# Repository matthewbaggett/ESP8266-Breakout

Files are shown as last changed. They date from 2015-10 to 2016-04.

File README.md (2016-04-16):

# ESP8266 Breakout

Originally just a ESP8266 broken out onto a 22pin DIP header, has become an ESP8266 on a 24pin DIP header with built in 3.3v regulator ([AMS1117](http://www.aliexpress.com/premium/ams1117.html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)), and built-in USB programmer ([CH340G](http://www.aliexpress.com/item/Free-shipping-50pcs-lot-CH340G-CH340-SOP16-IC-Best-quality/32420752742.html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)) and all the associated recommended pullups as per the [Arduino ESP8266 project](https://github.com/esp8266/Arduino) ([Schematic](https://github.com/esp8266/Arduino/blob/esp8266/docs/ESP_improved_stability.png)

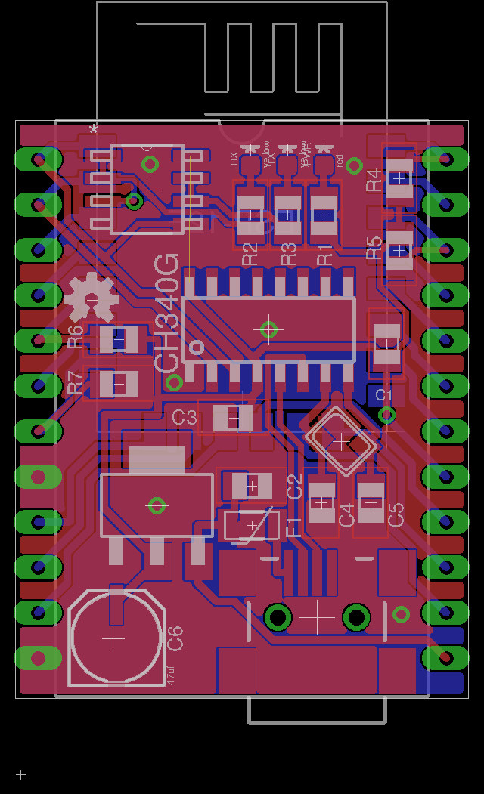
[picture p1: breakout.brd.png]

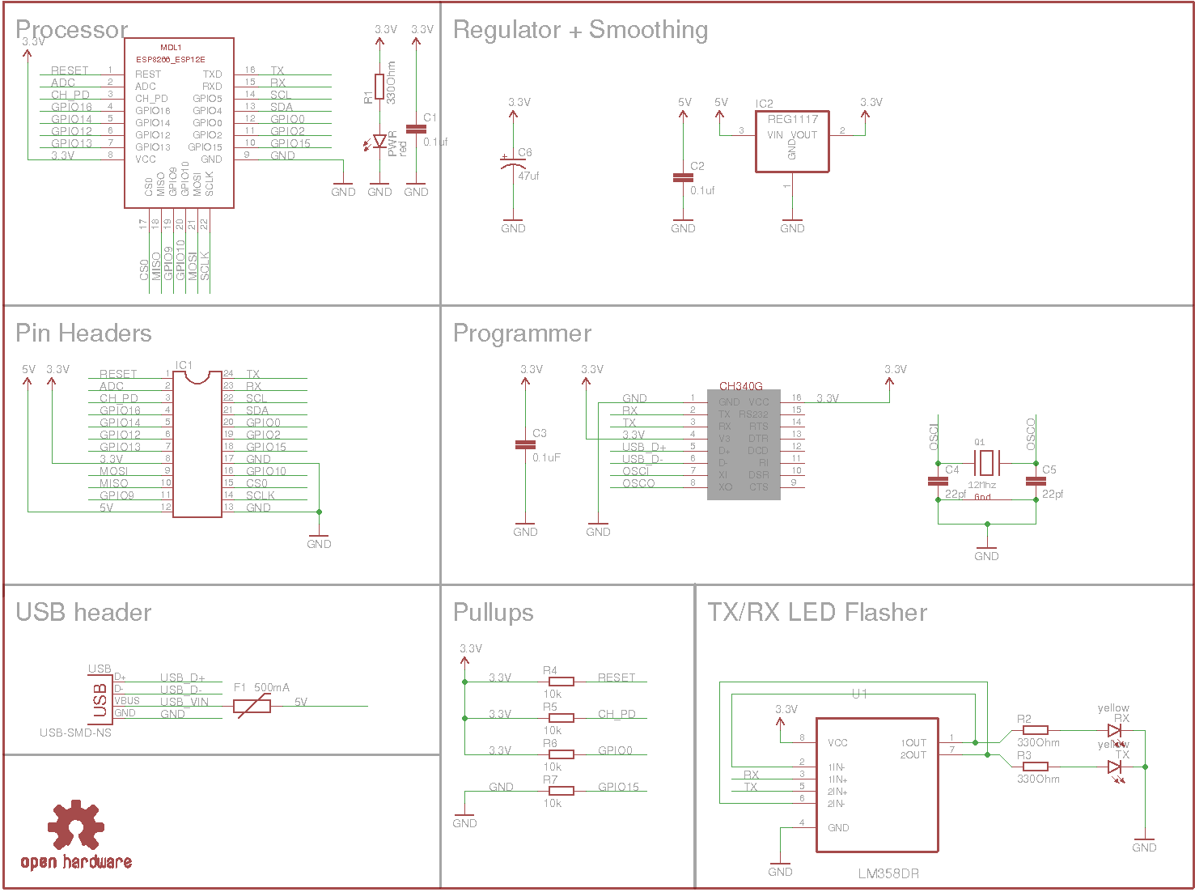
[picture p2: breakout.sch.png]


# Licence

<br />This work is licensed under a <a rel="license" href="http://creativecommons.org/licenses/by-nc/4.0/">Creative Commons Attribution-NonCommercial 4.0 International License</a>.

May be re-licenced on request.

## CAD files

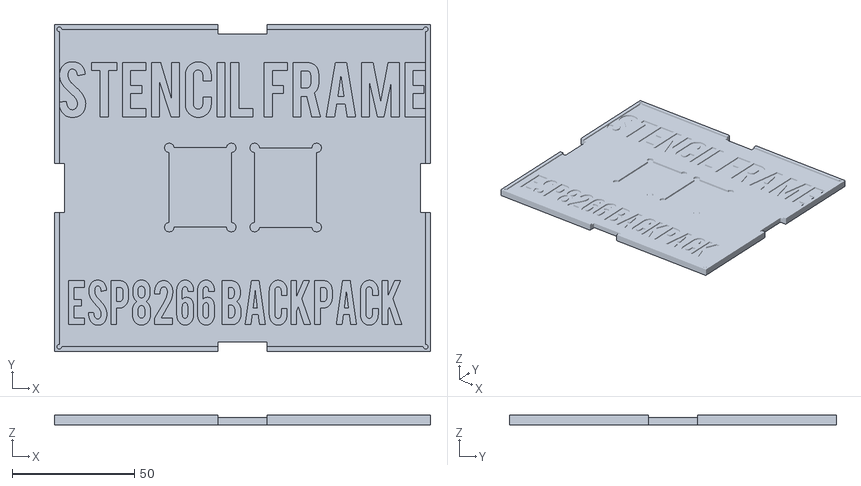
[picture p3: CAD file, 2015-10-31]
stencil_frame_esp8266_backpack.stl
154.0 x 134.0 x 4.00

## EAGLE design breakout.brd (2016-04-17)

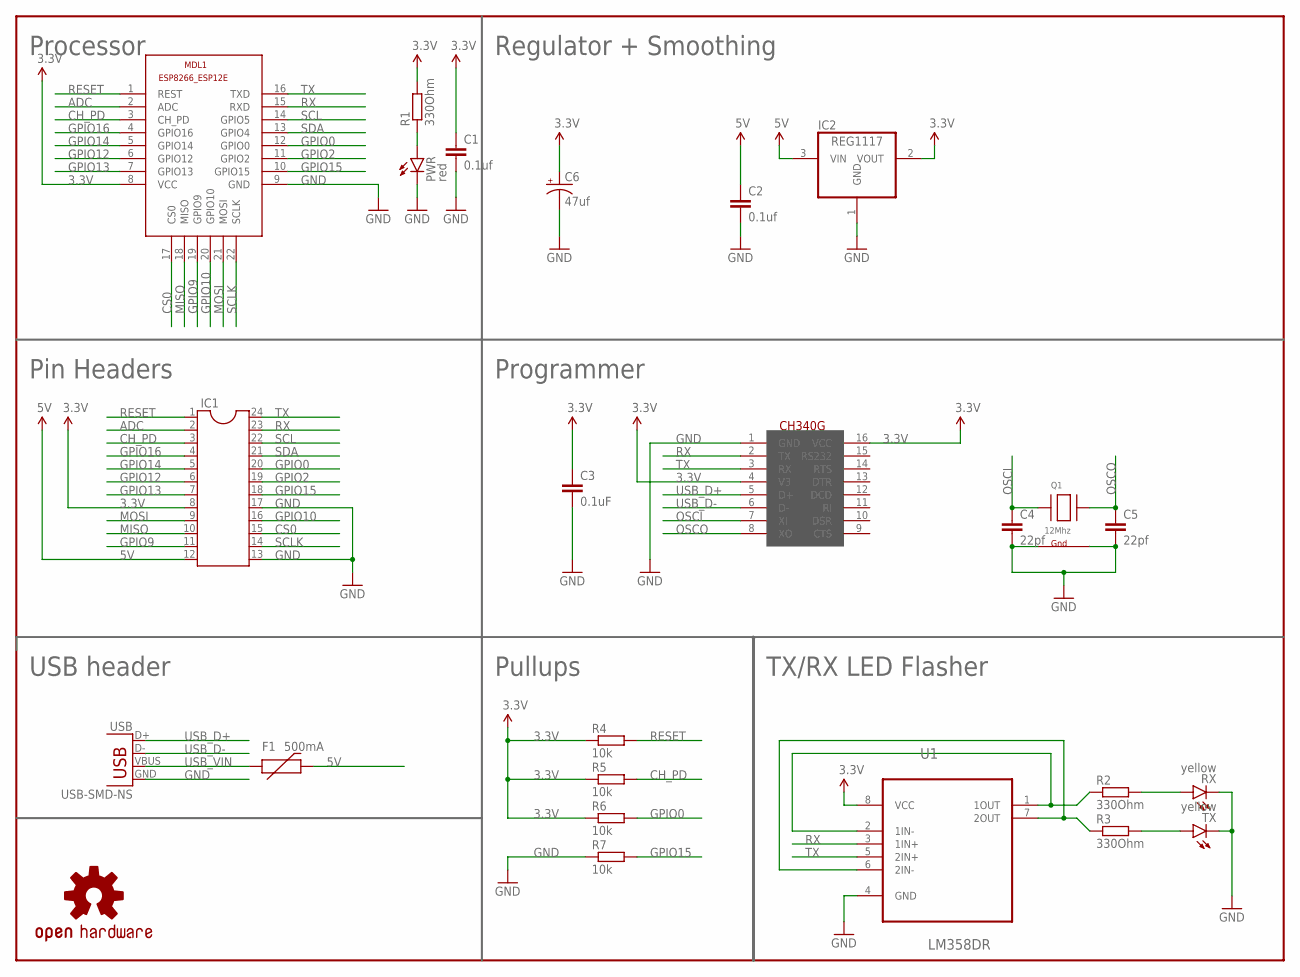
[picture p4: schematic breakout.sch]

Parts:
C1, C2: 0.1uf; C0805
C3: 0.1uF; C0805
C4, C5: 22pf; C0805
C6: 47uf; PANASONIC_C
F1: 500mA; PTC-1206
FRAME1: FRAME-LETTERNO_PACKAGE; DUMMY
IC1: DIL24-9
IC2: REG1117; SOT223
LOGO1: OSHW-LOGOS; OSHW-LOGO-S
MDL1: ESP8266-12EESP8266-ESP12E; ESP8266-ESP12E
PWR: red; LED-0603
Q1: 12Mhz; NX3225
R1, R2, R3: 330Ohm; R0805
R4, R5, R6, R7: 10k; R0805
RX: yellow; LED-0603
TX: yellow; LED-0603
U1: LM358DR; SOIC127P600X175-8N
U$1: CH340G; SOIC16
USB: USB-SMD-NS; USB-MINIB-NOSTOP

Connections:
3.3V: C1.1, C3.1, C6.+, IC1.8, IC2.2 (VOUT), MDL1.8 (VCC), R1.2, R4.1, R5.1, R6.1, U1.8 (VCC), U$1.4 (V3), U$1.16 (VCC)
5V: C2.1, F1.2, IC1.12, IC2.3 (VIN)
ADC: IC1.2, MDL1.2 (ADC)
CH_PD: IC1.3, MDL1.3 (CH_PD), R5.2
CS0: IC1.15, MDL1.17 (CS0)
GND: C1.2, C2.2, C3.2, C4.2, C5.2, C6.-, IC1.13, IC1.17, IC2.1 (GND), MDL1.9 (GND), PWR.C, Q1.2 (G2), Q1.4 (G1), R7.1, RX.C, TX.C, U1.4 (GND), U$1.1 (GND), USB.GND
GPIO0: IC1.20, MDL1.12 (GPIO0), R6.2
GPIO2: IC1.19, MDL1.11 (GPIO2)
GPIO9: IC1.11, MDL1.19 (GPIO9)
GPIO10: IC1.16, MDL1.20 (GPIO10)
GPIO12: IC1.6, MDL1.6 (GPIO12)
GPIO13: IC1.7, MDL1.7 (GPIO13)
GPIO14: IC1.5, MDL1.5 (GPIO14)
GPIO15: IC1.18, MDL1.10 (GPIO15), R7.2
GPIO16: IC1.4, MDL1.4 (GPIO16)
MISO: IC1.10, MDL1.18 (MISO)
MOSI: IC1.9, MDL1.21 (MOSI)
unnamed: PWR.A, R1.1
unnamed: R3.2, TX.A
unnamed: R2.1, U1.1 (1OUT), U1.2 (1IN-)
unnamed: R3.1, U1.6 (2IN-), U1.7 (2OUT)
unnamed: R2.2, RX.A
OSCI: C4.1, Q1.1 (X1), U$1.7 (XI)
OSCO: C5.1, Q1.3 (X2), U$1.8 (XO)
RESET: IC1.1, MDL1.1 (REST), R4.2
RX: IC1.23, MDL1.15 (RXD), U1.3 (1IN+), U$1.2 (TX)
SCL: IC1.22, MDL1.14 (GPIO5)
SCLK: IC1.14, MDL1.22 (SCLK)
SDA: IC1.21, MDL1.13 (GPIO4)
TX: IC1.24, MDL1.16 (TXD), U1.5 (2IN+), U$1.3 (RX)
USB_D+: U$1.5 (D+), USB.D+
USB_D-: U$1.6 (D-), USB.D-
USB_VIN: F1.1, USB.VBUS

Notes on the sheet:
Programmer
Regulator + Smoothing
Processor
Pin Headers
USB header
Pullups
TX/RX LED Flasher

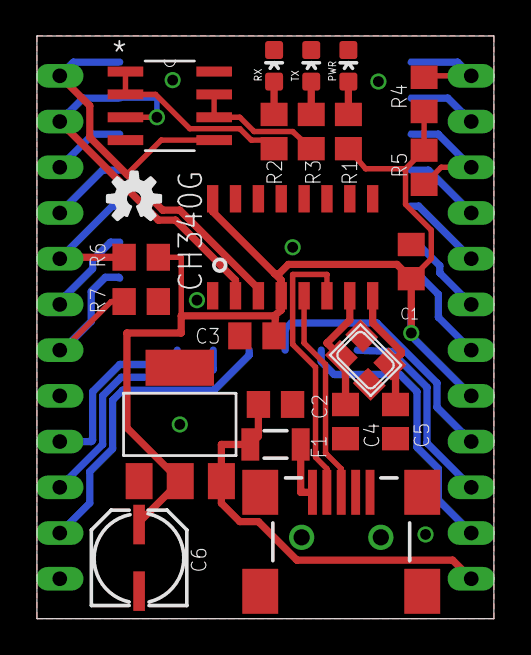
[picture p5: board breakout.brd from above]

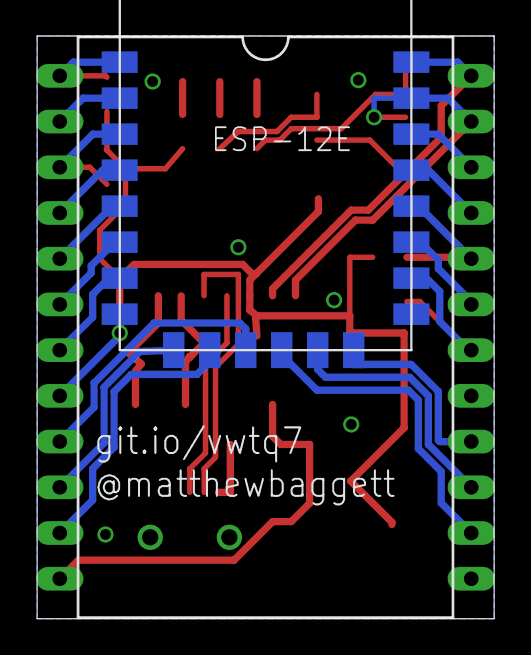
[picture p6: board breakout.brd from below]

Board: 2 copper layers, 25.4 x 32.4 mm, 26 parts (3 on the bottom side), 33 nets.

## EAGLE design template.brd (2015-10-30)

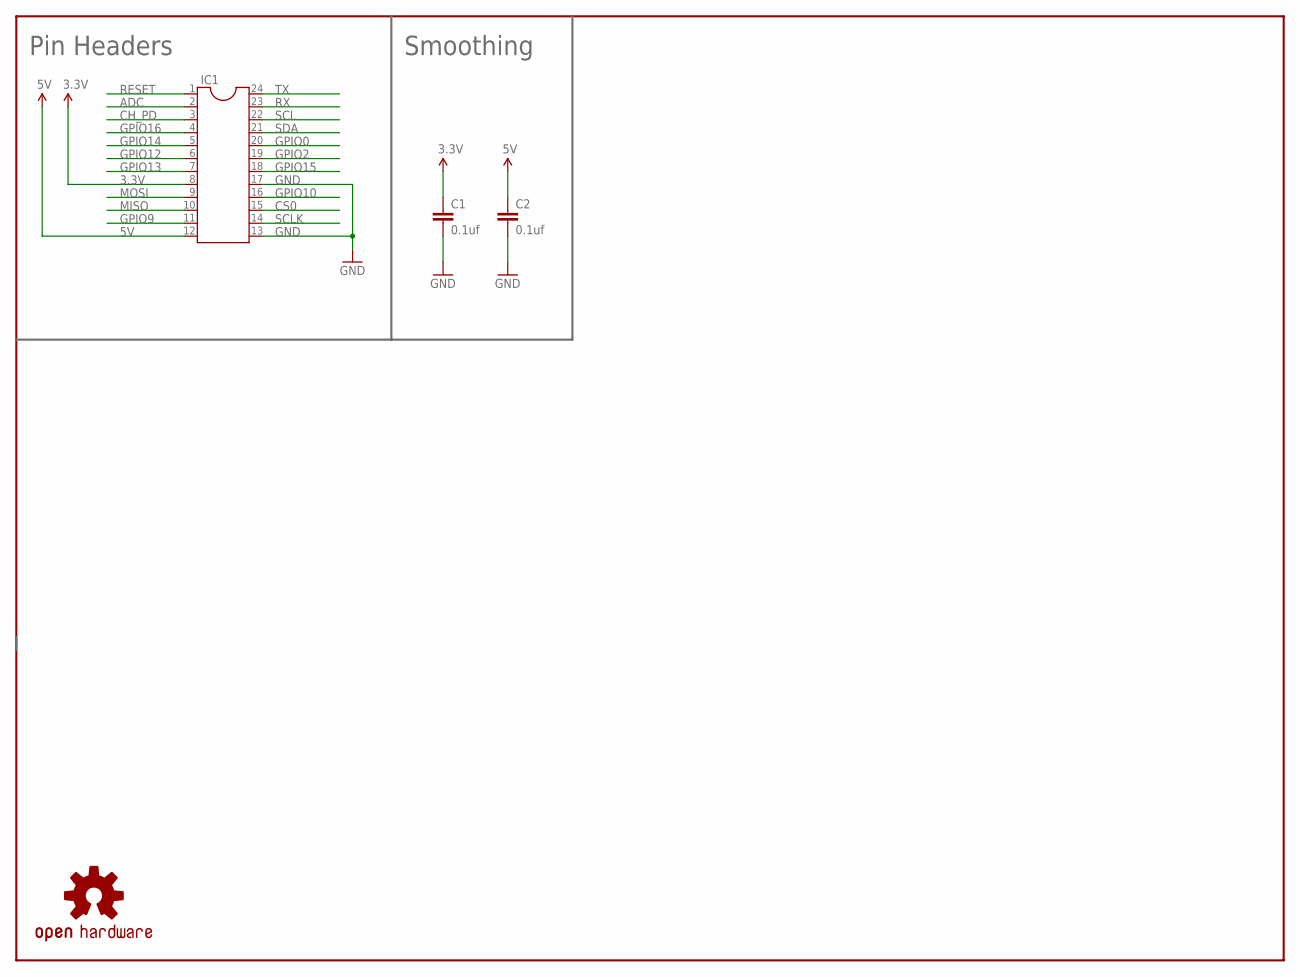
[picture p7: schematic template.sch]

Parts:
C1, C2: 0.1uf; 1206
FRAME1: FRAME-LETTERNO_PACKAGE; DUMMY
IC1: DIL24-9
LOGO1: OSHW-LOGOS; OSHW-LOGO-S

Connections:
3.3V: C1.1, IC1.8
5V: C2.1, IC1.12
ADC: IC1.2
CH_PD: IC1.3
CS0: IC1.15
GND: C1.2, C2.2, IC1.13, IC1.17
GPIO0: IC1.20
GPIO2: IC1.19
GPIO9: IC1.11
GPIO10: IC1.16
GPIO12: IC1.6
GPIO13: IC1.7
GPIO14: IC1.5
GPIO15: IC1.18
GPIO16: IC1.4
MISO: IC1.10
MOSI: IC1.9
RESET: IC1.1
RX: IC1.23
SCL: IC1.22
SCLK: IC1.14
SDA: IC1.21
TX: IC1.24

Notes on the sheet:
Pin Headers
Smoothing

Board: 2 copper layers, 5 parts (1 on the bottom side), 3 nets, no tracks yet.

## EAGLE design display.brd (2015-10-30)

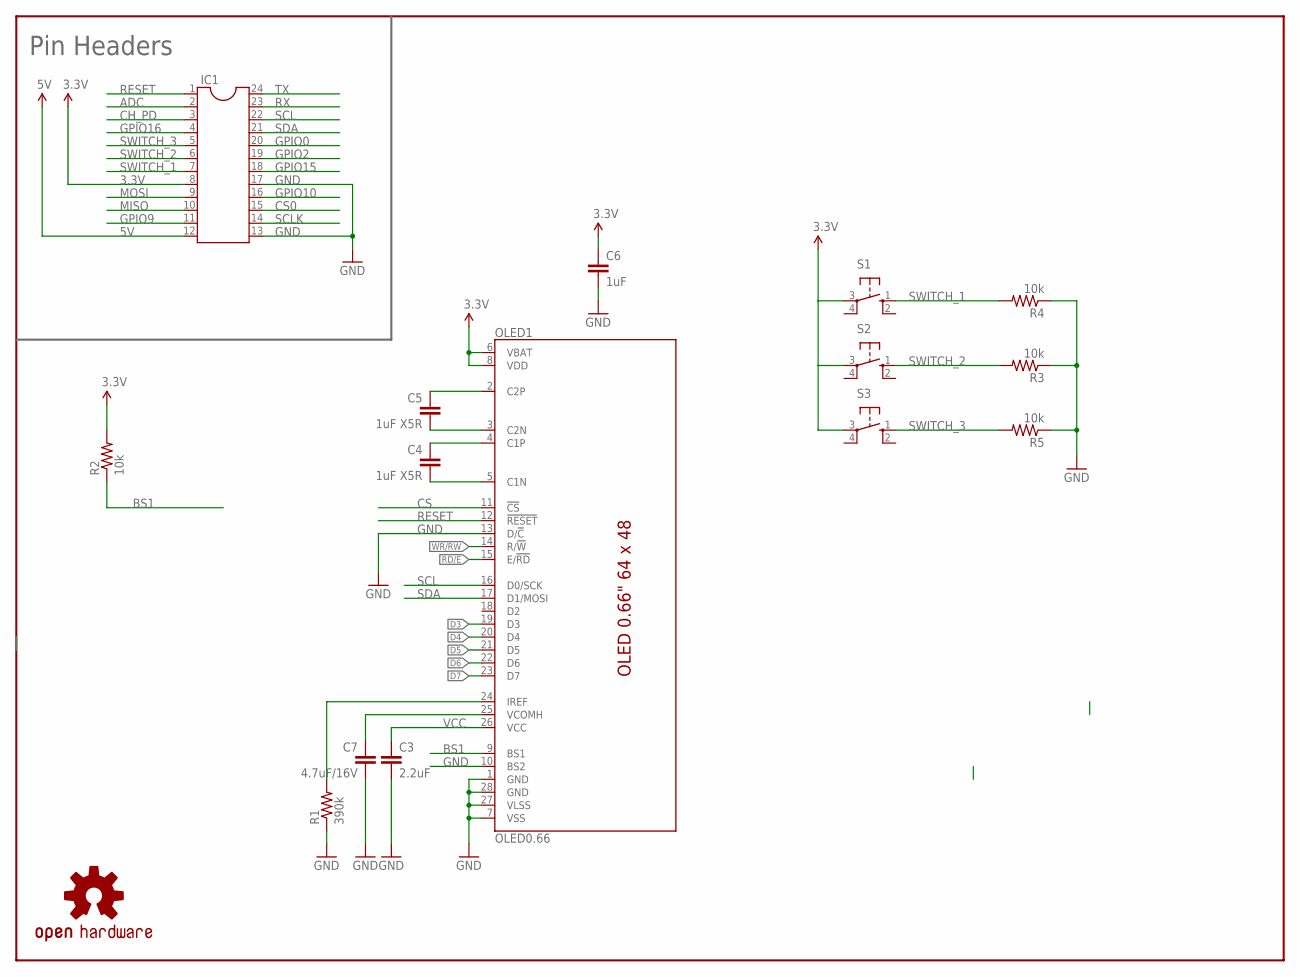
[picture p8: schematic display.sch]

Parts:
C3: 2.2uF; 1206
C4, C5: 1uF X5R; 1206
C6: 1uF; 1206
C7: 4.7uF/16V; 1206
FRAME1: FRAME-LETTERNO_PACKAGE; DUMMY
IC1: DIL24-9
LOGO1: OSHW-LOGOS; OSHW-LOGO-S
OLED1: OLED0.66; OLED-0.66-64X48
R1: 390k; 1206
R2, R3, R4, R5: 10k; 1206
S1, S2, S3: 10-XX; B3F-10XX

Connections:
3.3V: C6.1, IC1.8, OLED1.6 (VBAT), OLED1.8 (VDD), R2.2, S1.3, S2.3, S3.3
5V: IC1.12
ADC: IC1.2
BS1: OLED1.9 (BS1), R2.1
C1N: C4.2, OLED1.5 (C1N)
C1P: C4.1, OLED1.4 (C1P)
C2N: C5.2, OLED1.3 (C2N)
C2P: C5.1, OLED1.2 (C2P)
CH_PD: IC1.3
CS: OLED1.11 (!CS!)
CS0: IC1.15
D3: OLED1.19 (D3)
D4: OLED1.20 (D4)
D5: OLED1.21 (D5)
D6: OLED1.22 (D6)
D7: OLED1.23 (D7)
GND: C3.2, C6.2, C7.2, IC1.13, IC1.17, OLED1.1 (GND), OLED1.7 (VSS), OLED1.10 (BS2), OLED1.13 (D/!C!), OLED1.27 (VLSS), OLED1.28 (GND), R1.1, R3.1, R4.1, R5.1
GPIO0: IC1.20
GPIO2: IC1.19
GPIO9: IC1.11
GPIO10: IC1.16
GPIO15: IC1.18
GPIO16: IC1.4
IREF: OLED1.24 (IREF), R1.2
MISO: IC1.10
MOSI: IC1.9
RD/E: OLED1.15 (E/!RD!)
RESET: IC1.1, OLED1.12 (!RESET!)
RX: IC1.23
SCL: IC1.22, OLED1.16 (D0/SCK)
SCLK: IC1.14
SDA: IC1.21, OLED1.17 (D1/MOSI)
SWITCH_1: IC1.7, R4.2, S1.1 (S)
SWITCH_2: IC1.6, R3.2, S2.1 (S)
SWITCH_3: IC1.5, R5.2, S3.1 (S)
TX: IC1.24
VCC: C3.1, OLED1.26 (VCC)
VCOMH: C7.1, OLED1.25 (VCOMH)
WR/RW: OLED1.14 (R/!W!)

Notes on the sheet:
Pin Headers

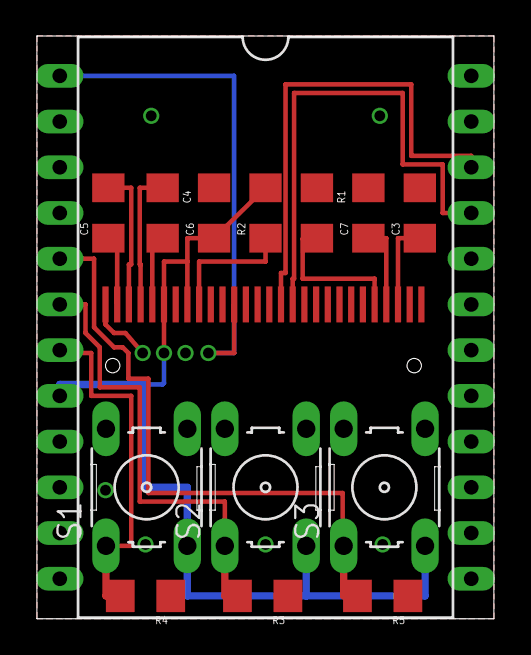
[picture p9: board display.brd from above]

Board: 2 copper layers, 25.4 x 32.4 mm, 17 parts (1 on the bottom side), 16 nets.

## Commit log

2015-10-09 Tidy up for publishing
    [breakout.brd, breakout.sch]
2015-10-10 Added FTDI + USB support on the board. Also cleaned up the schematic. DRC pass.
    [breakout.brd, breakout.sch]
2015-10-10 Slight revision to the GND plane.
    [breakout.brd]
2015-10-30 Adding a blank sheild
    [template.brd, template.sch]
2015-10-30 Adding a cute little OLED display based upon https://www.sparkfun.com/products/13003
    [display.brd, display.sch]
2015-10-30 Revision to switch around TX/RX lines so that this thing actually works, detach RTS signal from RESET, add TX & RX LEDs + assoc. resistors. Renamed GPIO4 & GPIO5 as SDA and SCL respectively to suit t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
    [breakout.brd, breakout.sch]
2015-10-30 Renamed GPIO4 & GPIO5 as SDA and SCL respectively to suit their default i2c states.
    [template.brd, template.sch]
2015-10-31 Stencil holder for DirtyPCBs stencils.
    [stencil_frame_esp8266_backpack.stl]
2015-10-31 Bigger knockouts to assist in removing stencil.
    [stencil_frame_esp8266_backpack.stl]
2015-12-23 Fix a DRC error..
    [breakout.brd]
2016-01-31 Updated images of the board and schematic to reflect the use of a CH340G instead of FTDI's FT232RL due to cost
2016-02-01 Added a polarised 47uf size B capacitor to the 3.3v rail. Removed thermals from fill layers
    [breakout.brd, breakout.sch]
2016-04-16 Fuck it, 0805 all the things, smaller crystal, rejig everything to solder in a less PITA way.
    [breakout.brd]
2016-04-16 Added TX/RX LEDs. Aww yiss.
    [breakout.brd, breakout.sch]
2016-04-17 Add labels
    [breakout.brd]

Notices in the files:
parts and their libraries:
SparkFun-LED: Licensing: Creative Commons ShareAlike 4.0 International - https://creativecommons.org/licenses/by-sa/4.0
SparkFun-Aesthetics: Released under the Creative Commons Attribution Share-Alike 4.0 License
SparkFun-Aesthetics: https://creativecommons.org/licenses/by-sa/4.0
